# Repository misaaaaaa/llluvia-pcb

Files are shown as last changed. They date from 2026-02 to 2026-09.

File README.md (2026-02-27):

# llluvia-pcb

Circuito generador de gotas de lluvia lumínicas y sonoras

Foto de alguien manipulando la placa
Fotografía por Carolina Miguieles en la inauguración de la muestra

## Descripción

El circuito utiliza un transistor NPN de manera que genera un ruido rosa. Con la base conectada a negativo, el emisor a positivo y el colector desconectado, se genera una conducción inversa a través de la unión base-emisor. Esta configuración crea fluctuaciones aleatorias de corriente que producen variaciones similares al ruido rosa, lo que asemeja el sonido de una lluvia torrencial. Esta señal es llevada a un comparador simple, al que por medio de un potenciómetro se puede controlar cuantas "gotas" se dejan pasar.

## Especificaciones

- Alimentación sugerida de 12 a 15v DC centro positivo
- Alimentación vía batería 23A o fuente de poder DC
- Potenciómetro de control de "gotas"
- Potenciómetro de control de nivel
- Salida para auriculares o de línea (revisar bugs)

## Contexto

La pcb fue diseñada para la exposición "Llluvia Metropolitana", exhibida en enero de 2026 en la Galería Metropolitana junto a Rainer Krause. Se produjeron tres modelos, todos con la misma electrónica, pero con una cita, traducción o paráfrasis distinta en cada una:

"[...] ya va a llover, ya va a llover, ya va a llover, ya va a llover, [...]" - Steve Reich

"pensar en el evento pluvial del carniense: 
la lluvia de 2 millones de años hace 234 millones de años (*archifósil*)" - Quentin Meillassoux

"¿la lluvia pertenece al mundo material, o solo los charcos que deja en zanjas y baches?" - Tim Ingold

## Bugs conocidos

- Para trabajar conectado a una fuente DC se sugiere retirar la batería de 12V 23A, ya que según el circuito solo se desconecta si ambas entradas JACK DC tienen algo conectado
- La salida L y R del conector de audio están puenteadas, por lo que si se conecta un plug MONO (TS) como los del formato Eurorack la salida se aterriza y no suena. Se sugiere intervenir la placa y romper la pista que conecta ambas salidas si se va a utilizar de esta manera. Si se usa con audífonos o con un cable TRS no hay inconvenientes.

## Bom

[Lista de materiales en formato CSV](./llluvia-bom.csv)

| Reference | Cantidad | Value | Footprint | Comentario | Link de referencia |
|---|---|---|---|---|---|
| C1,C2 | 2 | 1u | Condensador no polarizado 5.1mm x 3.2mm - Pitch 5.00mm | | ~ |
| D1,D3,D4 | 3 | LED | Led 3mm cabeza plana | Montaje invertido (por parte trasera de la placa) | <https://www.railwayscenics.com/flat-warm-white-water-clear-resistor-reqd-p-4583.html> |
| D2 | 1 | 1N4007 | Diodo THT TO-41 | | <http://www.vishay.com/docs/88503/1n4001.pdf> |
| J2,J3 | 2 | JACK_DC | Conector Barrel Jack 2.1mm x 5.5 mm | | <https://es.rs-online.com/web/p/conectores-de-alimentacion-dc/2858785> |
| J4 | 1 | ON/OFF | Pin header 2p 2.54mm | | <https://no.rs-online.com/web/p/pcb-headers/2518086> |
| J5 | 1 | AudioJack2_Ground_Switch  | Jack audio TRS 3.5mm modelo CUI SJ1-3525N | | <https://forum.digikey.com/t/cui-sj1-3525n-series-3-5mm-audio-jack-suffix-information/6667> |
| Q2 | 1 | 2N2222A | Transistor 2n2222a THT | | <https://www.victronics.cl/transistores/transistor-pn2222a-npn-06a-40v-to92-10u/> |
| R1 | 1 | 1M | Resistencia 1/4w | | ~ |
| R2 | 1 | 470k | Resistencia 1/4w | | ~ |
| R3 | 1 | 220 | Resistencia 1/4w | | ~ |
| R4,R6,R7,R8,R11 | 5 | 1k | Resistencia SMD 0805 | Para practicar soldadura SMD a mano :D | ~ |
| R5,R9,R10 | 3 | 100k | Resistencia SMD 0805 | Para practicar soldadura SMD a mano :D | ~ |
| RV1,RV2 | 2 | 100k | Potenciómetro PCB tipo RV09 o PTV09A Vertical | | <https://es.rs-online.com/web/p/potenciometros/7377827> |
| U1 | 1 | LM324 | Circuito Integrado DIP-14 + Socket | | <http://www.ti.com/lit/ds/symlink/lm2902-n.pdf> |
| BT1 | 1 | Batería 12V A23 + Soporte | 12v A23 battery holder THT | Solo si se quiere usar con batería | <https://www.jsumo.com/battery-holder-1-x-23a-with-pins> |

## Esquemático

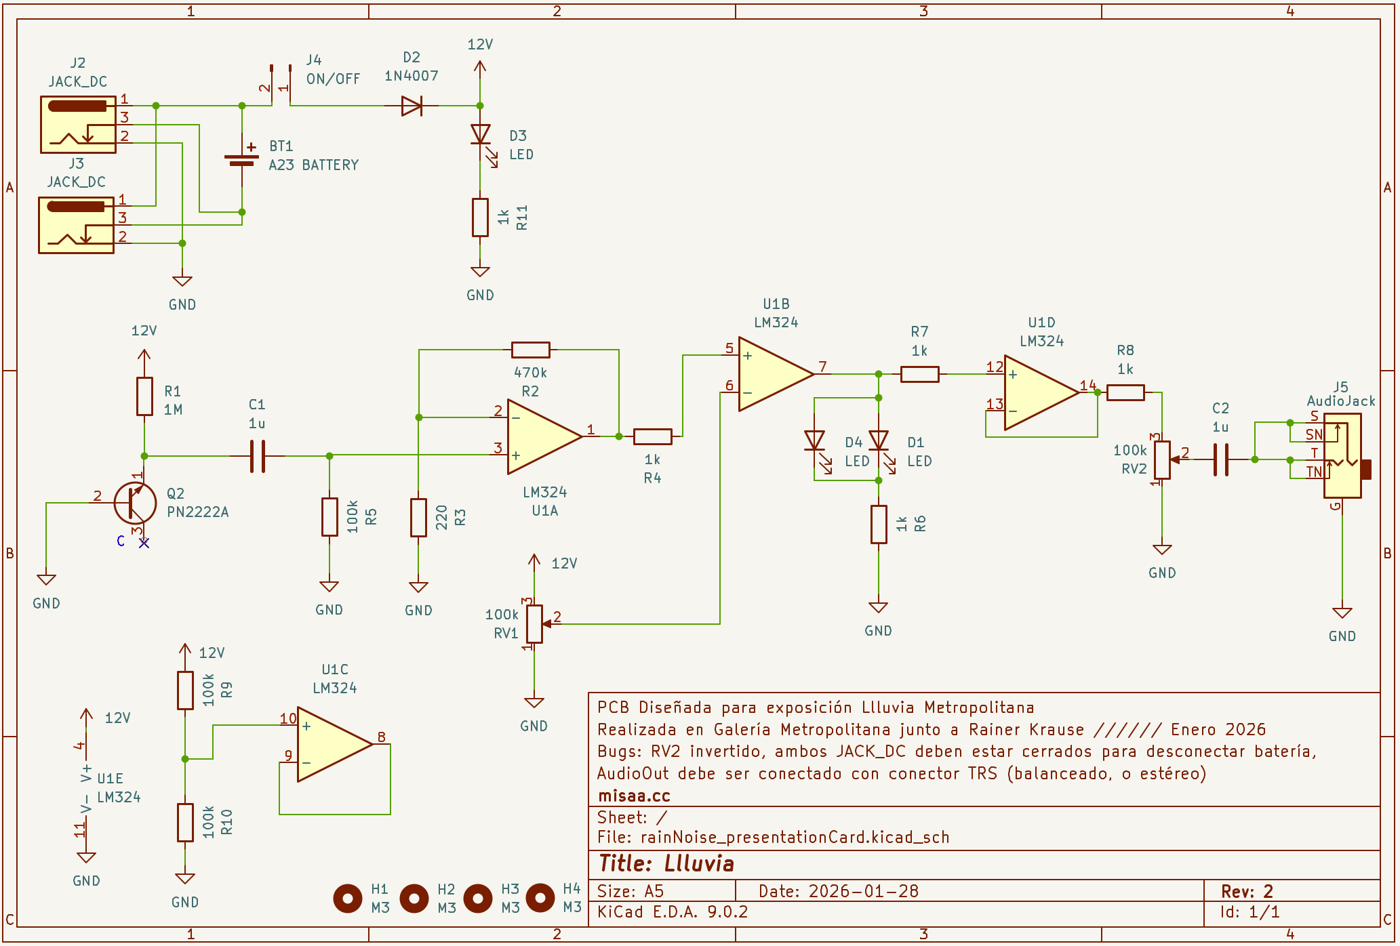
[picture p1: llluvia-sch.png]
Esquemático


## Imágenes

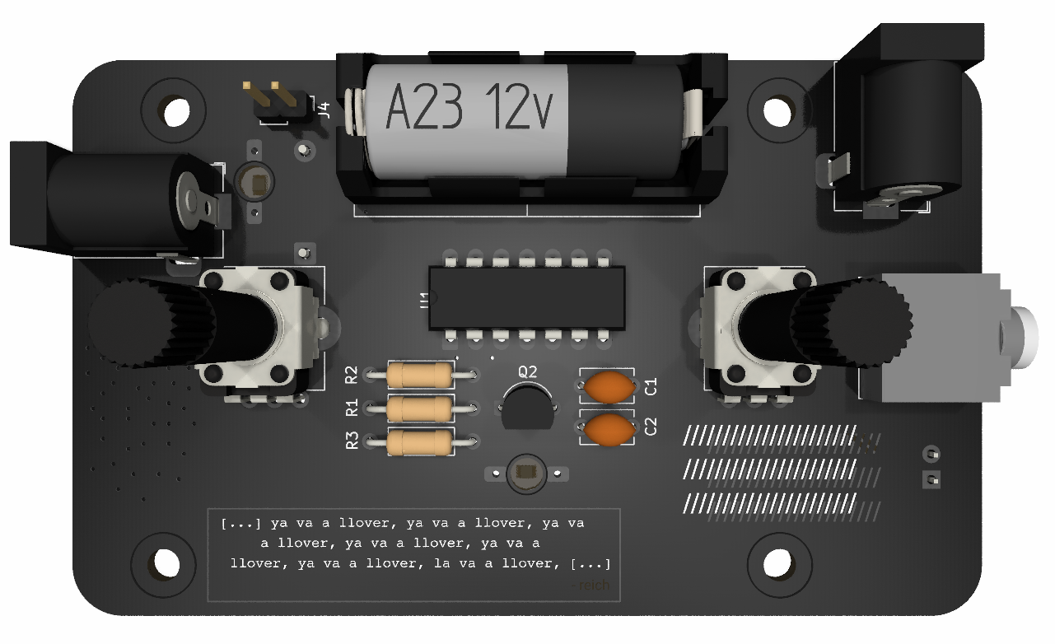
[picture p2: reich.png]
Pcb reich

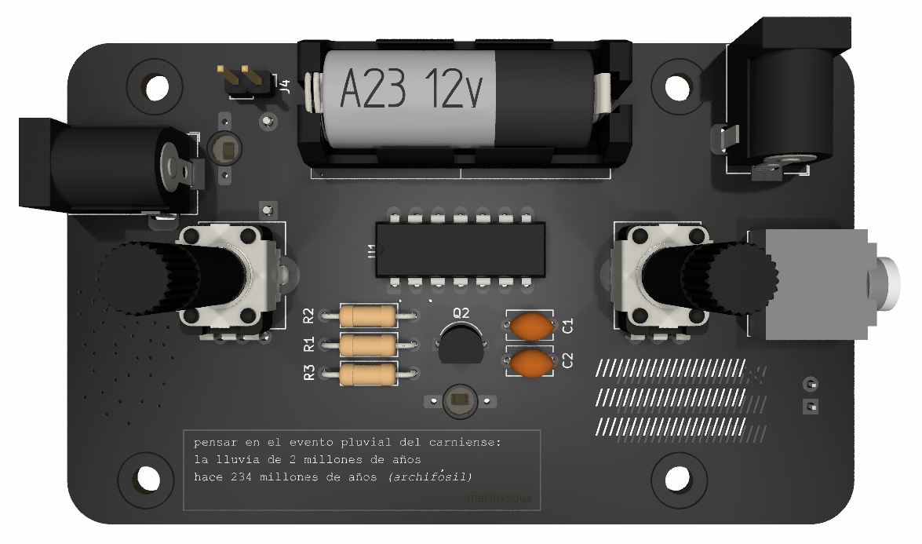
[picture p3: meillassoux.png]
Pcb meillassoux

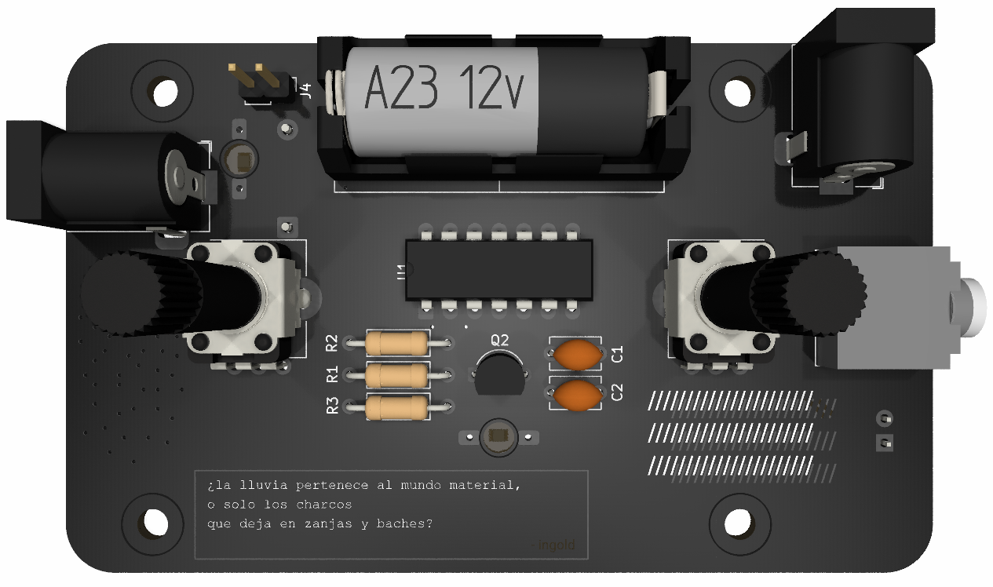
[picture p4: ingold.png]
Pcb ingold

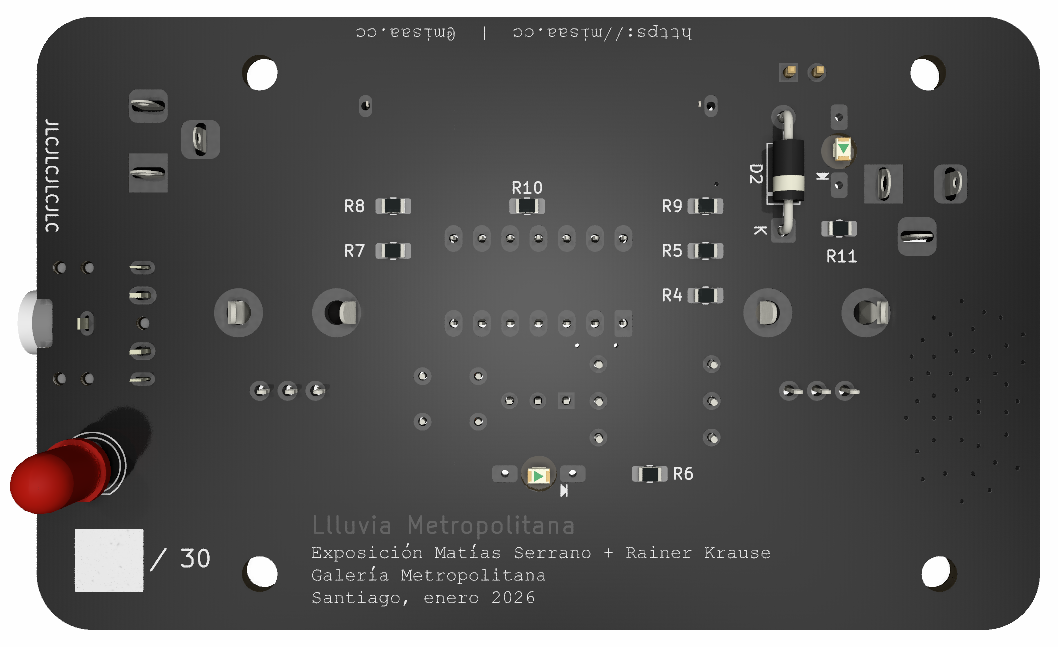
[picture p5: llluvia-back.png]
Pcb Back


## Video de referencia (01:40)

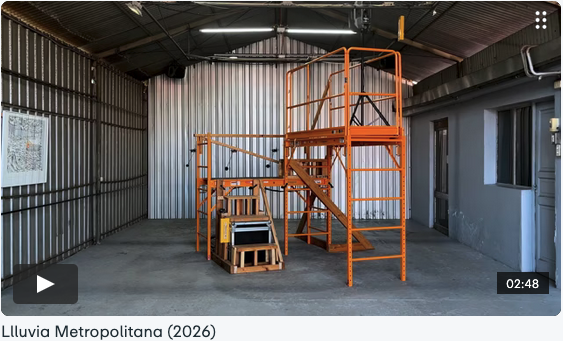
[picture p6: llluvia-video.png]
Video (https://vimeo.com/1167776803?fl=pl&fe=sh#t=1m41s)


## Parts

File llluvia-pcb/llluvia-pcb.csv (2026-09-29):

Reference | Value | Datasheet | Footprint | Qty | DNP
BT1 | A27 BATTERY | ~ | LIBRERIAS:Battery_23A | 1
C1,C2 | 1u | ~ | Capacitor_THT:C_Disc_D5.1mm_W3.2mm_P5.00mm | 2
D1,D3,D4 | LED | ~ | LED_THT:LED_D5.0mm,LIBRERIAS:LED_PCBasDiffuser | 3
D2 | 1N4007 | http://www.vishay.com/docs/88503/1n4001.pdf | Diode_THT:D_DO-41_SOD81_P10.16mm_Horizontal | 1
J2,J3 | JACK_DC | ~ | Connector_BarrelJack:BarrelJack_Horizontal | 2
J4 | ON/OFF | ~ | Connector_PinHeader_2.54mm:PinHeader_1x02_P2.54mm_Vertical | 1
J5 | AudioJack2_Ground_Switch | ~ | Connector_Audio:Jack_3.5mm_CUI_SJ1-3525N_Horizontal | 1
Q2 | PN2222A | https://www.onsemi.com/pub/Collateral/PN2222-D.PDF | Package_TO_SOT_THT:TO-92_Inline_Wide | 1
R1 | 1M | ~ | Resistor_THT:R_Axial_DIN0207_L6.3mm_D2.5mm_P10.16mm_Horizontal | 1
R2 | 470k | ~ | Resistor_THT:R_Axial_DIN0207_L6.3mm_D2.5mm_P10.16mm_Horizontal | 1
R3 | 220 | ~ | Resistor_THT:R_Axial_DIN0207_L6.3mm_D2.5mm_P10.16mm_Horizontal | 1
R4,R6,R7,R8,R11 | 1k | ~ | Resistor_SMD:R_0805_2012Metric_Pad1.20x1.40mm_HandSolder | 5
R5,R9,R10,RV1,RV2 | 100k | ~ | Potentiometer_THT:Potentiometer_Bourns_PTV09A-1_Single_Vertical,Resistor_SMD:R_0805_2012Metric_Pad1.20x1.40mm_HandSolder | 5
U1 | LM324 | http://www.ti.com/lit/ds/symlink/lm2902-n.pdf | Package_DIP:DIP-14_W7.62mm_LongPads | 1

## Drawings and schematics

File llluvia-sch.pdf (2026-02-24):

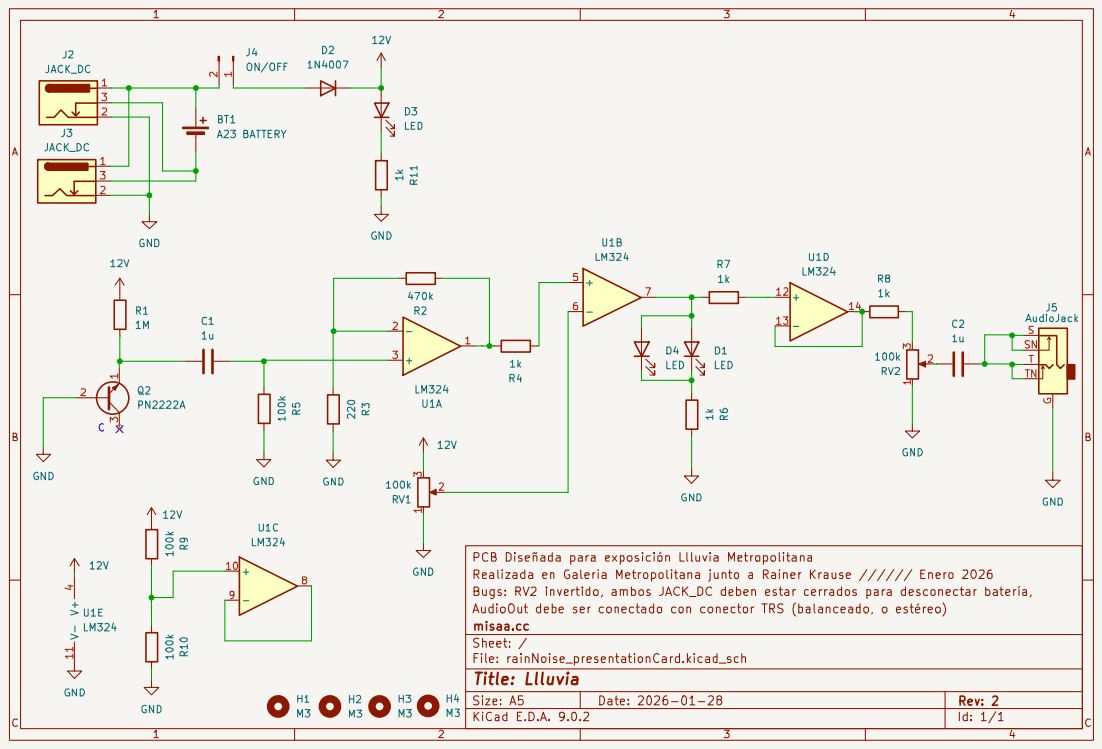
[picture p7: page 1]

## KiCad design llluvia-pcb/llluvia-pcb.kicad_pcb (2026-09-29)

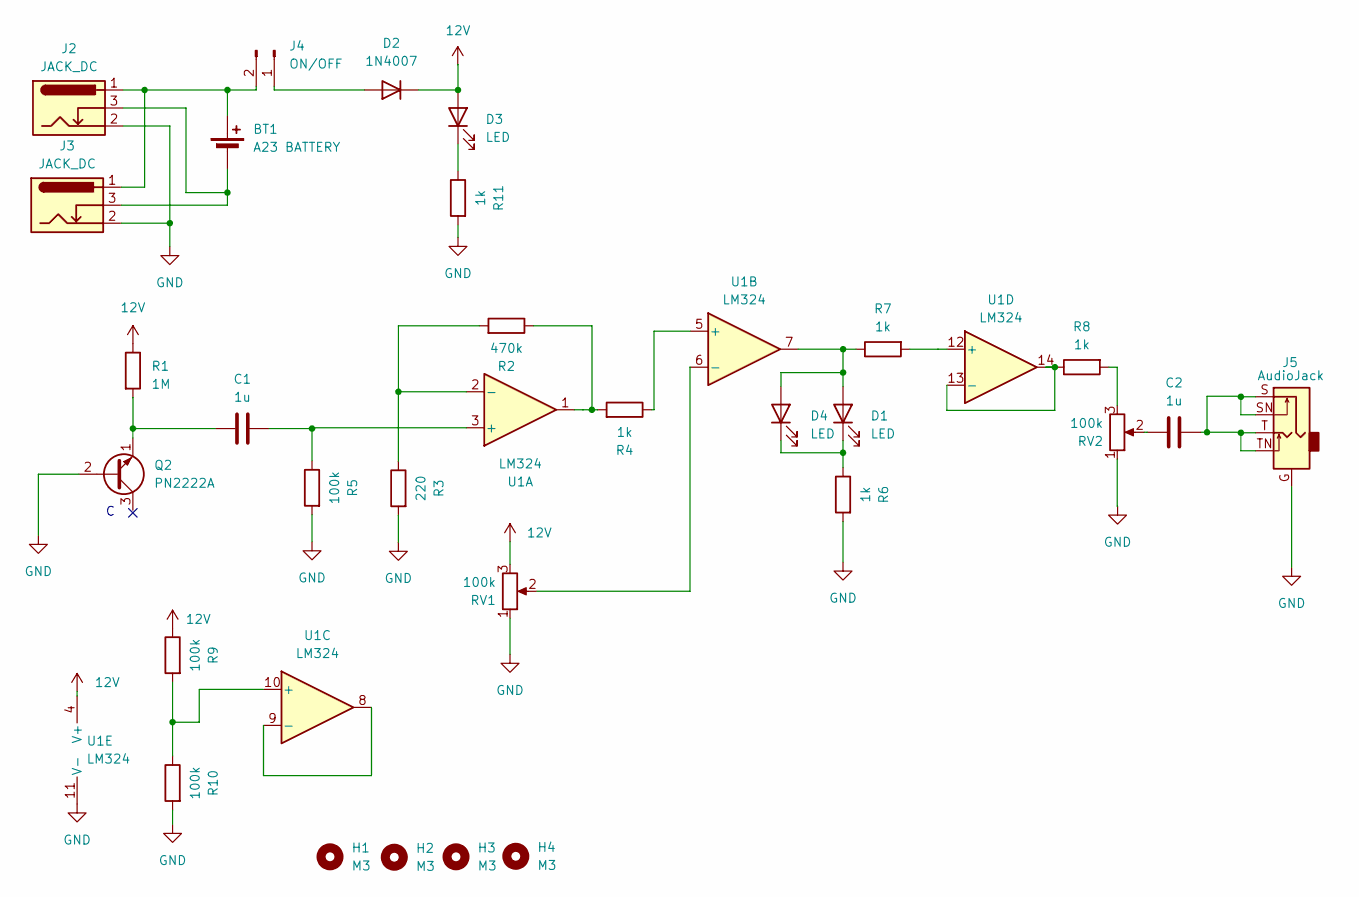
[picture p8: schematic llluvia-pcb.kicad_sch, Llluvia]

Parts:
BT1: A23 BATTERY; Battery_23A
C1, C2: 1u; C_Disc_D5.1mm_W3.2mm_P5.00mm
D1, D3: LED; LED_PCBasDiffuser
D2: 1N4007; D_DO-41_SOD81_P10.16mm_Horizontal
D4: LED; LED_D5.0mm
H1, H2, H3, H4: M3; MountingHole_3.2mm_M3
J2, J3: JACK_DC; BarrelJack_Horizontal
J4: ON/OFF; PinHeader_1x02_P2.54mm_Vertical
J5: AudioJack; Jack_3.5mm_CUI_SJ1-3525N_Horizontal
Q2: PN2222A; TO-92_Inline_Wide
R1: 1M; R_Axial_DIN0207_L6.3mm_D2.5mm_P10.16mm_Horizontal
R2: 470k; R_Axial_DIN0207_L6.3mm_D2.5mm_P10.16mm_Horizontal
R3: 220; R_Axial_DIN0207_L6.3mm_D2.5mm_P10.16mm_Horizontal
R4, R6, R7, R8, R11: 1k; R_0805_2012Metric_Pad1.20x1.40mm_HandSolder
R5, R9, R10: 100k; R_0805_2012Metric_Pad1.20x1.40mm_HandSolder
RV1, RV2: 100k; Potentiometer_Bourns_PTV09A-1_Single_Vertical
U1: LM324; DIP-14_W7.62mm_LongPads

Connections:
12V: D2.1 (K), D3.2 (A), R1.1, R9.1, RV1.3, U1.4 (V+)
GND: J2.2, J3.2, J5.G, Q2.2 (B), R3.2, R5.2, R6.2, R10.2, R11.2, RV1.1, RV2.1, U1.11 (V-)
unnamed: BT1.1 (+), J2.1, J3.1, J4.2
unnamed: BT1.2 (-), J2.3, J3.3
unnamed: C2.1, RV2.2
unnamed: C2.2, J5.S, J5.SN, J5.T, J5.TN
unnamed: D1.2 (A), D4.2 (A), R7.1, U1.7
unnamed: D1.1 (K), D4.1 (K), R6.1
unnamed: D2.2 (A), J4.1
unnamed: D3.1 (K), R11.1
unnamed: C1.1, Q2.1 (E), R1.2
unnamed: R2.1, R4.2, U1.1
unnamed: R8.2, RV2.3
unnamed: C1.2, R5.1, U1.3 (+)
unnamed: R2.2, R3.1, U1.2 (-)
unnamed: R4.1, U1.5 (+)
unnamed: RV1.2, U1.6 (-)
unnamed: R9.2, R10.1, U1.10 (+)
unnamed: U1.8, U1.9 (-)
unnamed: R7.2, U1.12 (+)
unnamed: R8.1, U1.13 (-), U1.14

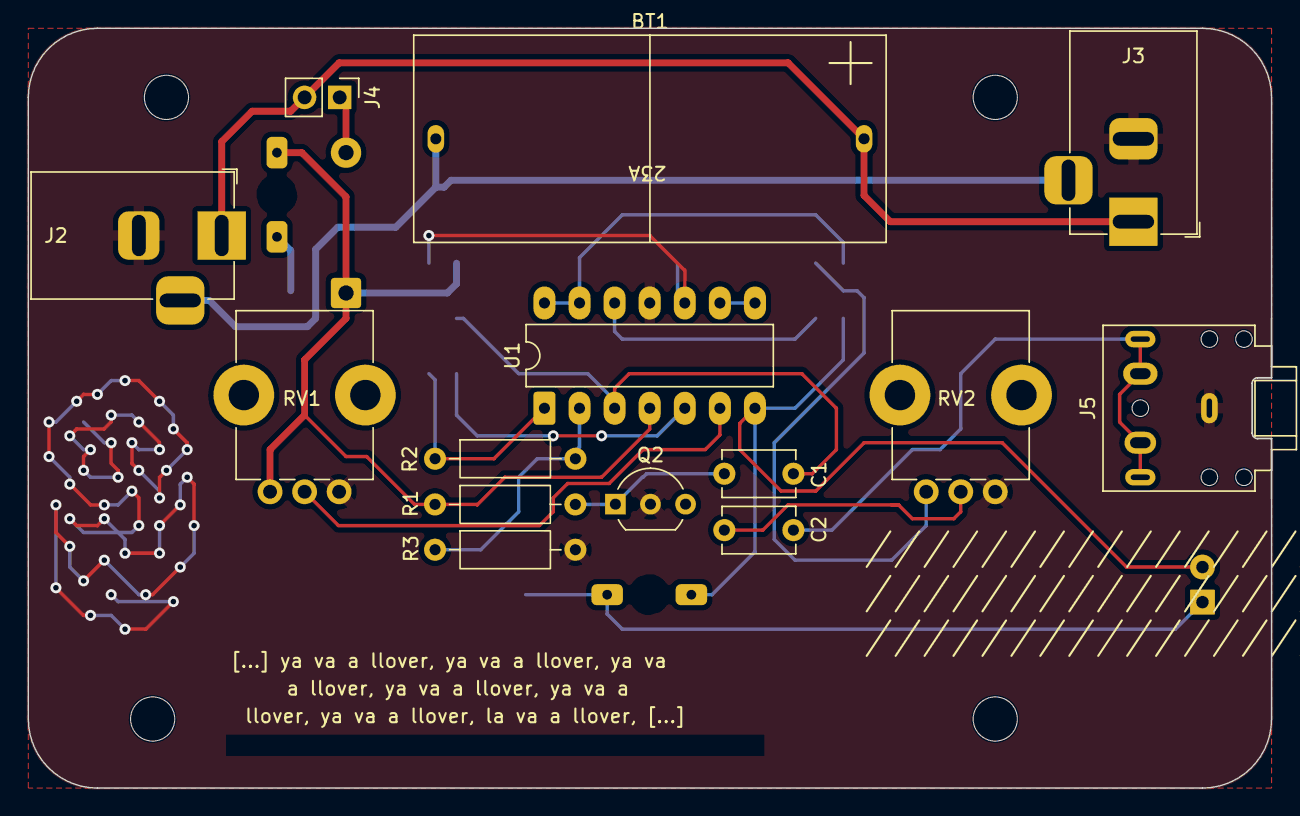
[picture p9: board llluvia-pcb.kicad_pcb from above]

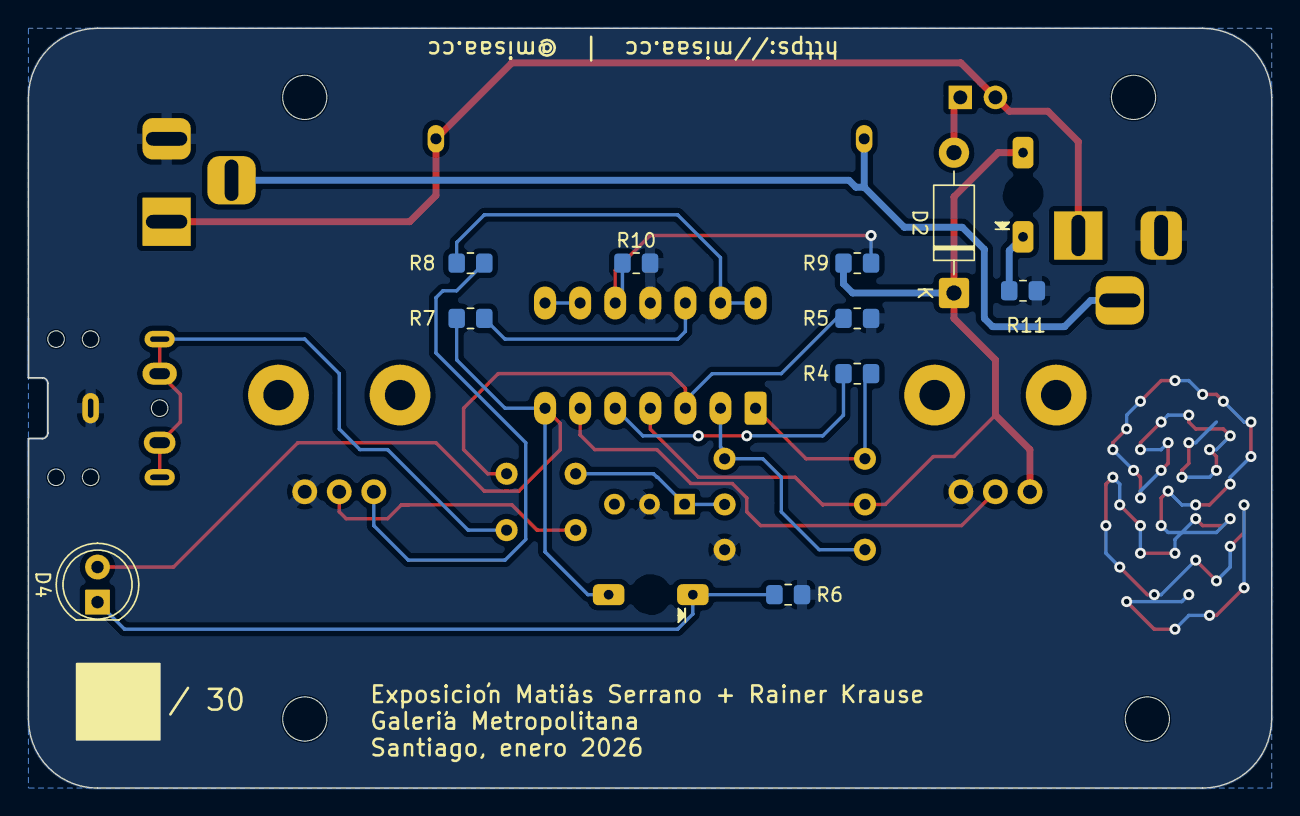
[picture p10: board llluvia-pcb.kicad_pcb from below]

Board: 2 copper layers, 90.0 x 55.0 mm, 30 parts (10 on the bottom side), 21 nets.

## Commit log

2026-02-24 añadida información circuito
    [llluvia-bom.csv]
2026-09-29 añadida pcb
    [llluvia-pcb.csv, llluvia-pcb.kicad_pcb, llluvia-pcb.kicad_sch]
